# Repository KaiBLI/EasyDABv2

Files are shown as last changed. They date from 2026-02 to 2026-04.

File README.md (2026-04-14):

# EasyDABv2
Repository of info for Sergiy's EasyDABv2 DAB Exciter Board. This is not to be confused with the EasyDABv1 which is a USB-based DAB exciter board. The USB DAB Board requires a computer to handle modulation while the v2 board utilizes a FPGA for independent operation.

Assembled EasyDAB6 v2 Boards. PCBs printed with JLCPCB.

Front-side of the EasyDAB6 v2 Board
Back-side of the EasyDAB6 v2 Board

# Introducton
First off, much of this is not my original work, credit goes to Sergiy for the design and release of the EasyDAB board. His site can be found here: https://tipok.org.ua/node/46

Secondly, this is a repository of the information I've learned through trying to manufacture one of these boards myself in order that folks in the future have an easier time with it than me.
There are a couple of issues I've had to contend with, firstly, I have not been able to find a license or any information regarding copyright of this board. Given that this was done in collaboration with the OpenDigitalRadio group, it is assumed that the board was released under similar licensing to the other projects under OpenDigitalRadio, that is permitting deriative work which is also licensed under the GPL and with credit to the original creator. 

If the above is not correct and the board was released under a more restrictive license, please get in touch at hoosk@retrohoosk.tv and this repository will be updated as such. That being said, under no circumstances will documentation of my own making be removed that was created based on information that is publicly available. 

# Aims
As mentioned in the introduction, the information is somewhat sparse on how to go about creating one of these boards. The original release was an Eagle PCB project coupled with a release of the firmware for flashing the board. 

As I'm a believer in easy, accessible and transparent documentation, I have determined to document my findings and provide as much information as possible regarding the manufacture and configuration of these boards. 

So the aims of this project encompass the following:

1. Documentation

I will proceed to create an 'info dump' of all of my findings that I've learned through building this projects.

Status: 90% Done

2. Photos

I will proceed to create high-resolution and detailed photos of both empty boards and fully assembled units so that others can see what these look like once assembled.

Status: 90% Done - Still need to add empty board pictures, only have renders at this point.

3. A fresh bill of materials.

The existing bill of materials leave too much up to assumption, therefore I will create a digikey cart and an Excel sheet of components required including example part numbers. It is assumed that components over time will be obsoleted and substitutes will be required, hence specification of components will be detailed as possible.

Status: Done!

4. New Features

The board already supports DRM and FM modulation in addition to DAB/DAB+, theoretically additional FPGA core/firmware could be built for other digital modulation such as HDRadio/NRSC5 and DVB. This would require input from additional contributors familiar with FPGA programming.

Status: Help Needed

# Images 
Exported Board Renders from KiCAD:
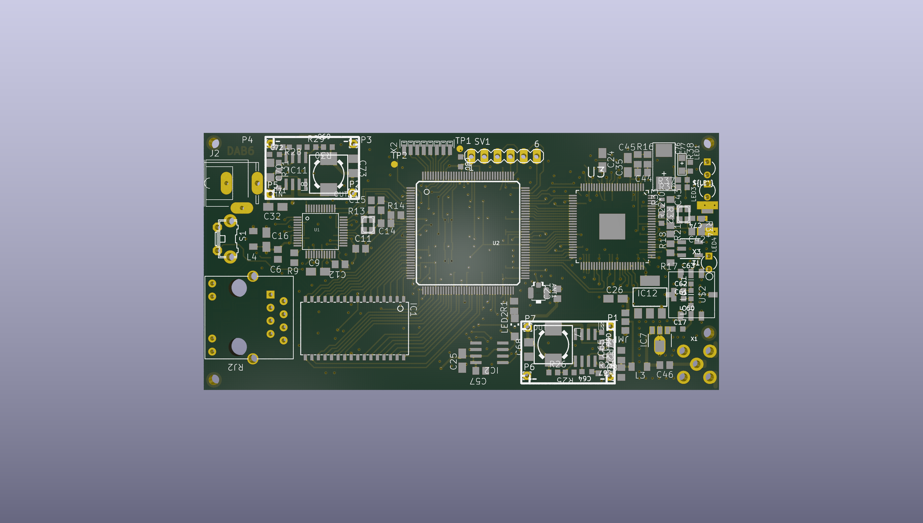
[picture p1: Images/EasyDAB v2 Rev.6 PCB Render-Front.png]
EasyDAB6v2 Front Board Render

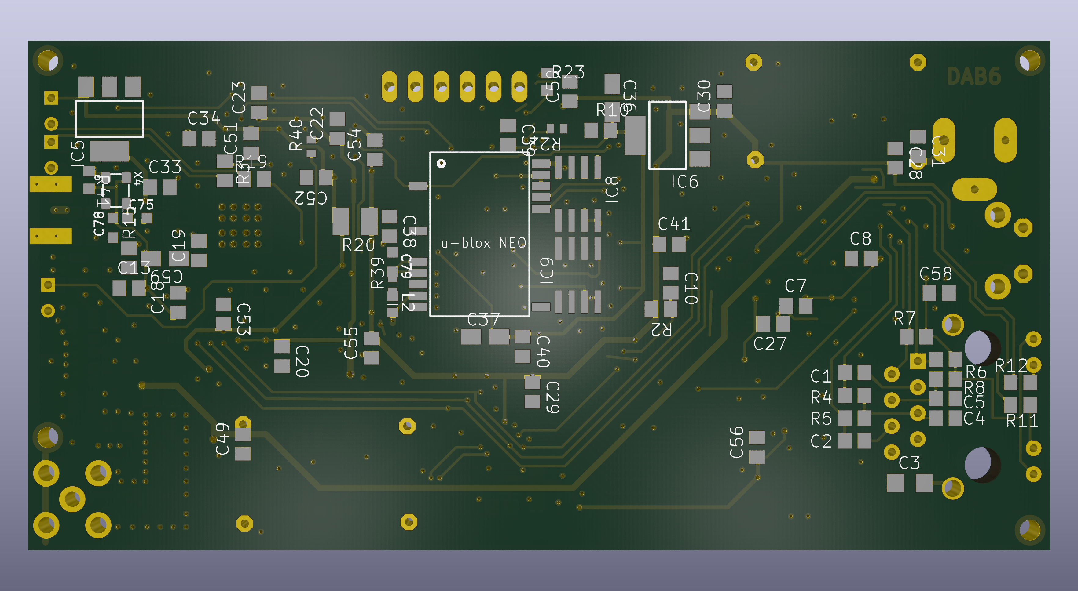
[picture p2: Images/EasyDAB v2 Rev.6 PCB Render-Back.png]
EasyDAB6v2 Back Board Render


The below are two separate concurrently operating multiplexes created using the ODR-mmbTools including ODR-DabMux, ODR-AudioEnc and ODR-PadEnc. ODR-PadEnc takes text from a file to create the DLS scrolling text and PNGs from a directory to create station logos, it then is exposed on a socket that AudioEnc can pull to add to the audio stream. ODR-AudioEnc is used to pull internet radio stations, convert them to MPEG-1 Layer II at 48kHz and provide them over an EDI or ZMQ stream to ODR-DabMux. ODR-DabMux is then used to create a DAB ensemble which is a collection of radio stations, programme data and other data compliant with the DAB standard which can then be sent to the EasyDAB modulator using ZMQ.

Home-made DAB Mux with American Radio Stations
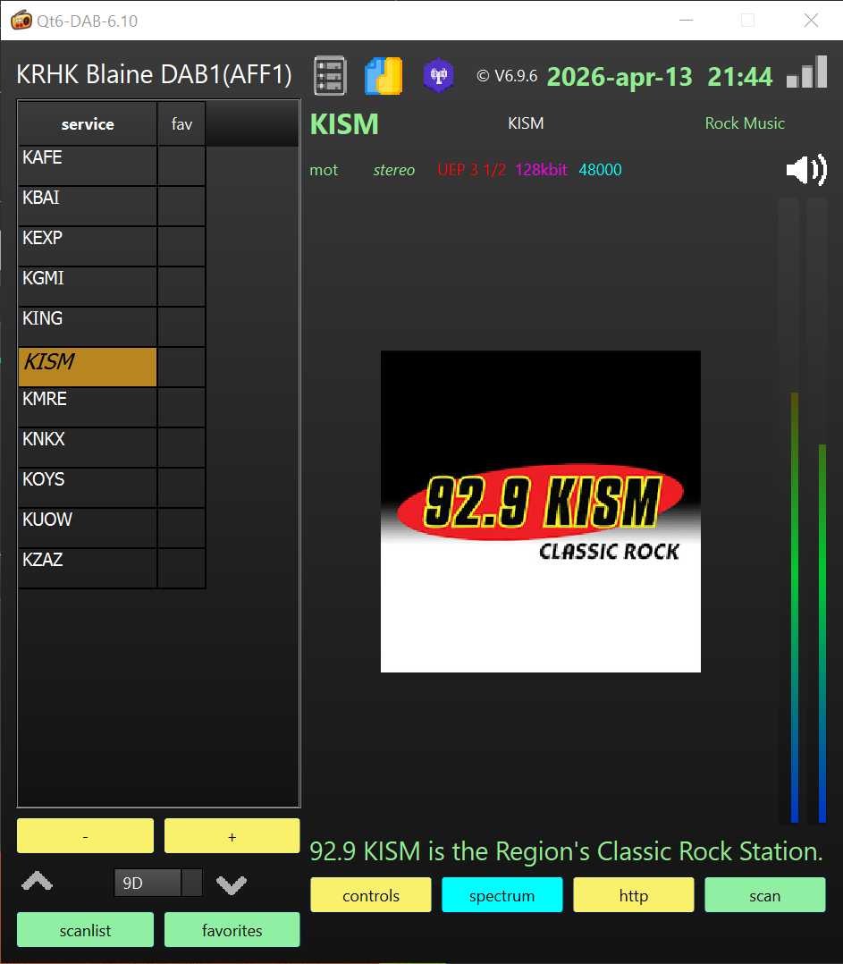
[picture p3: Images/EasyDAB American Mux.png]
Home-made DAB Mux with American Stations from Northwest Washington


Re-created BBC National DAB mux broadcasting in NW Washington
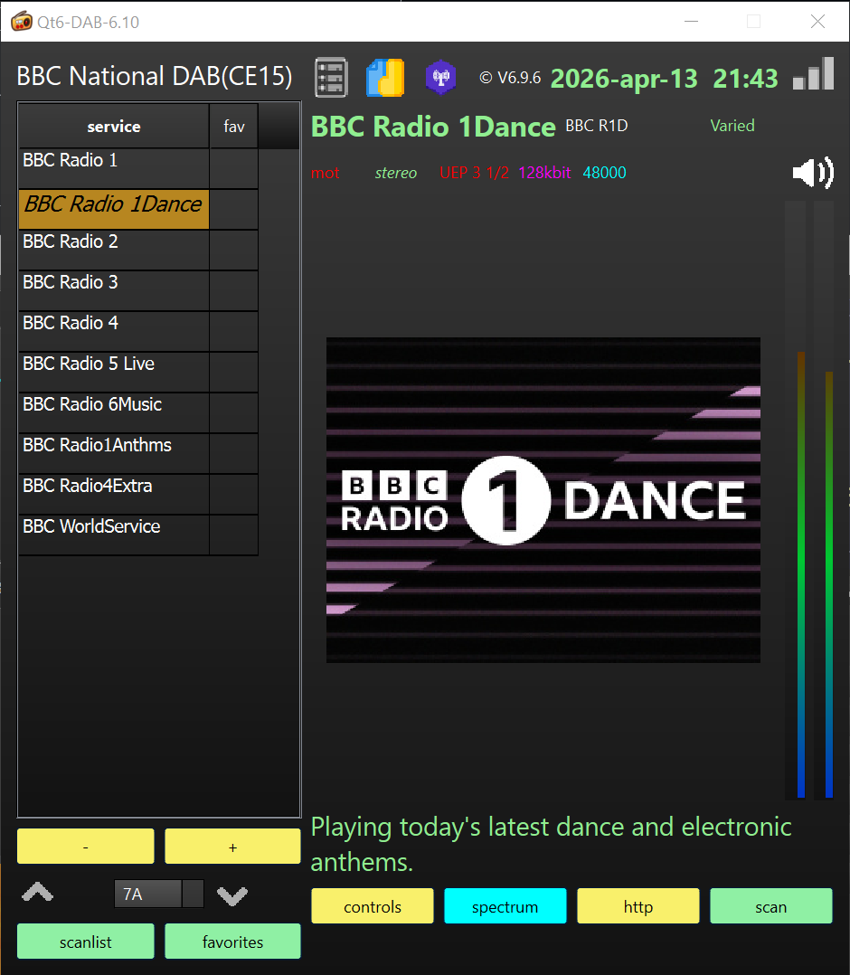
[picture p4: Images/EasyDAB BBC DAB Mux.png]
Home-made DAB Mux with re-created BBC Radio Stations in the legacy DAB Standard


Output from Qt6-DAB's SpectrumScope of the Re-created BBC National DAB Mux
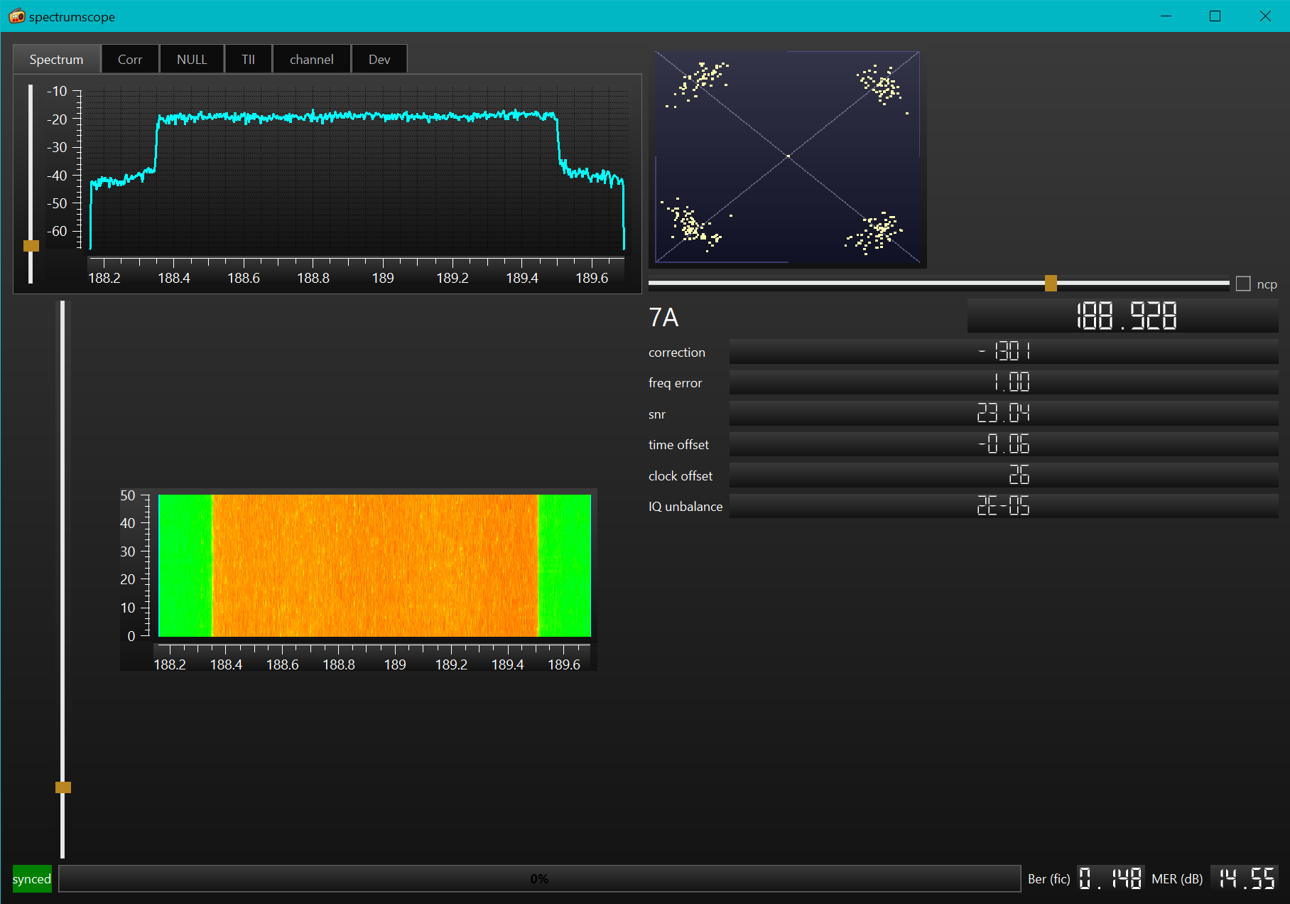
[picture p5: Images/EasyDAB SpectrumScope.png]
QT6 Spectrumscope for the re-created BBC DAB Mux


# Contact
Questions and Comments can be directed to hoosk@retrohoosk.tv , I'd love to hear your experience with assembling one of these boards and other ideas for this repo.

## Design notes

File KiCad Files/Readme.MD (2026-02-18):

# KiCAD PCB Map and Schematic
The current design of the EasyDAB PCB has a silkscreen with component labels covered by a myriad of solder pads. It is therefore essential for you to be familiar with the PCB map to accurately locate where components should go. You should not trust the PCB silkscreen to be accurate or clear on where things should go and should not be relied on. The PCB Map can be viewed by the KiCad PCB Editor, by using the search function, KiCad will highlight the appropriate solder pads for each component.

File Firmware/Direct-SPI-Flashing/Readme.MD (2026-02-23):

#This Folder Contains firmware for flashing direct to the SPI Flash

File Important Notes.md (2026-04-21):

# Noise on EasyDABv2 Cold Start
The current schematics have an issue which causes a lot of noise on cold-start which require a 2K Ohm resistor bodge. Please see here for more info: https://tipok.org.ua/node/56 - It is warned that you will burn out your output amplifier if you do not address this.

# Units are not provided for the below caps on the schematic, the correct units are Pico Farad, NOT Micro Farad. 

Thank you to PancakePuppy for confirming values.

C42 C43 - 27pF

C46 C47 - 100pF

These caps above are only required if you're using the Quartz oscillator. You do not need to install them if you are using the VCTCXO. 

# CY7C1019DV33 SRAM Chip

The main SRAM chip is designed in a socketed package, but it is generally surface mounted on this board, this can cause bad solder joints. 

If you are getting partial/no audio and evidence of corrupt DAB frames, validate the solder joints on the main SRAM, this will likely be your problem. The FPGA can appear to be fully functional with this problem happening and the only problem be the lack of audio, trust me, check the main SRAM! 

This part is End-of-Life, so it may become difficult to acquire in the future. 

# C76 Charge Pump Capacitor

If you have elected to use the VCTCXO instead of a standard Quartz Oscillator, contrary to popular belief the relatively expensive charge pump capacitor is not required for the board to operate correctly if you are not using SFN. It has not been tested without being present when configured for SFN. Please report in if you have had success without the charge-pump cap with SFN.

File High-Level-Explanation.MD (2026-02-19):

# The EasyDAB v2 Board
# What is it?
The EasyDAB v2 board is a DAB Radio exciter. It allows you to broadcast a digital radio signal compliant with DAB/DAB+ specifications that can be received on compatible DAB Digital Radios sold across Europe, certain parts of Asia and Australia.

# What is DAB?
DAB stands for Digital Audio Broadcasting, it is standard for broadcasting a digital radio signal in 55 countries around the world. It's the result of a European research project and publicly released in 1995 with consumer grade radios appearing in the late 90s. 

DAB found its earliest successes and populized widly across the UK thanks to the efforts of Pure, who manufacturered a variety of radios at a price point that was reasonable to the average consumer. The BBC and other broadcasters in the UK rapidly embraced the standard and by the early 2000s there were two national multiplexes as well as around 5 regional multiplexes broadcasting which allowed a user within range of a DAB transmitter to pick up around 40-60 radio stations broadcasting a mix of audio dramas, talk/news radio, sports as well as vast array of stations broadcasting a dynamic range of music genres. 

DAB however had a number of false starts and was abandoned in a number of other countries and only later found success with the launch of DAB+, a revision to the original standard which utilizes AAC-MP4 a codec that doubles the efficiency of transmitted audio, allowing multiplex operators to double the number of stations broadcast with no reduction of audio quality. Some countries are making plans to discontinue the use of FM radio in favor of DAB with Norway becoming the first country in the world to switch off FM broadcasts in favor of DAB+ in 2017.

The original standard of DAB utilizing MPEG-1 Layer II audio is starting to fall into disuse, the UK remaining the only country with regular DAB broadcasts with most commercial stations having switched over to the more efficient DAB+ standard. At present only the BBC National Stations as well as a small handful of commercial stations continue to broadcast in the older standard. DAB+ cannot be used by radios manufactured to the original standard and is likely to be a source of significant electronic waste in the UK.

The disuse of the original standard and the subsequent tsunami of electronic waste generated by the disposal of the earlier DAB radios popularized in the 2000s in the UK drove me to sink my teeth into this project by carrying out small-scale original DAB broadcasts here in Washington State. I'm originally from the UK, but moved over to the Pacific Northwest in 2018 bringing my DAB radios with me. They've been effective paperweights the last few years, but with this project I hope to bring them back to life, as well as preserve a selection of Pure Radio models released in the 2000s. At present I own a Pure Evoke 1, Pure Tempus 1S, Pure PocketDAB 1500 and a Pure DRX-601EX serial number 391. The Pure DRX-601EX was the first semi-portable DAB radio released, but at a high price point of GBP 500 and accordingly few were sold. DAB became popularized with the release of the Pure Evoke 1, the first sub GBP 100 DAB radio, meaning that everyone was able to get on board with DAB in the early 2000s in the UK.

# What about the Americas? 
Okay, I had to put this question in as I'm based in the US. No country in the Americas uses DAB at the time of writing. The US and Canada instead adopted Ibiquiti's IBOC (In Band On Channel) standard, officially known to the FCC as NRSC5, and to the general population as HD Radio. HD Radio is a very different standard to DAB whereby HD Radio will sandwich an analog FM or AM signal allowing the receiver to dynamically switch between analog and digital as signal conditions permit. 

DAB on the other hand uses Band III (174Mhz-240Mhz) with a wider carrier, this allows more stations to be broadcast on a single frequency and works better for countries with more centralized broadcasting approaches, while IBOC suits the highly decentralized radio market of the US. 

Of an interesting note, Canada originally did small scale experimentation with DAB on the L Band, however this was abandoned in favor of using the same standard as the US. Utilization of the L Band was removed from the DAB specification in January 2017. 

Digital Terrestrial Radio has seen lesser usage in the US and Canada due to the popularization of Satellite Radio on the L Band thanks to SiriusXM. 
Band III in the US is allocated for VHF System M Digital TV Channels 7-13 (174Mhz-216Mhz) as well as Amateur, Land Mobile, Fixed in the 216-240Mhz ranges.

# How does the EasyDAB v2 Board Work?
The EasyDAB v2 board requires a DAB Multiplex (also known as an Ensemble) to be configured and running on a server, this can be acheived by using the OpenDigitalRadio (ODR) Tools, specifically ODR-AudioEnc to process an audio source into a compatible format for DAB use and ODR-DabMux to build an Ensemble. Additionally you may want to use ODR-PadEnc to provide Programme Additional Data to your broadcasted stations. For reference, a multiplex/ensemble is a collection of audio and data services packaged together and provided in a ZMQ or ETI stream to be received by the EasyDAB board.

The EasyDAB board has a Xilinx Spartan 6 FPGA configured to handle the DAB modulation after which it sends the data to a Digital Synthesiser to generate the digital frequency. It then passes through a mini baulin to step up the frequency strength, through either a low pass filter or a band pass filter (Depending on your config), through a Low Noise Amplifier and out to a SMA Jack to a broadcast antenna. The generated signal can then be received on DAB/DAB+ hardware. 

If you are using a Low Pass Filter, you can load alternative firmware onto the board to broadcast FM or Digital Radio Mondiale signals.

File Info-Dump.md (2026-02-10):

# EasyDAB v2 Assembly Options
The EasyDAB v2 is a versitile board allowing for usage with transmitting a DAB ensemble from a single board and using multiple EasyDAB v2 boards to extend the range of your broadcast ensemble. If you wish to build for usage with a SFN there are additional components and considerations you need to make which are covered in this document. Additionally, you can build initially for non-SFN usage and later add the SFN components to enable that functionality. SFN does add a significant cost to the assembly of the board, so you will probably only want to use those components if you are certain you want to go down the SFN route, and that to gain any benefit from purchasing those components you will actually need to double up that order as SFN requires at least two EasyDAB v2 boards. The author of this document has yet to experiment with SFN usage, so much of this information I have obtained by examining schematics and obtaining information from other members of the OpenDigitalRadio Telegram group. Big thanks to Rash for providing some high-level information that has allowed me to sink my teeth into this project. 

This document also covers your options for acheiving RF filtering, which is a non-optional step you must take to avoid polluting the RF spectrum with harmonics as well as the decision whether to utilize the Mini360 DC-DC converter modules or source our own equivalent components for directly soldering on the board. 

As a word of advice for people starting out, I would suggest startin off with the options installing the Mini360 modules, the RBP-204+ band pass filter and electing to -not- install the SFN components.

Final bit of advice, I would suggest gaining some experience with soldering before engaging on this project. A number of the ICs such as the FPGA and Digital Synthesiser are fairly expensive and have a very high pin density. Good solder, good flux, a steady hand as well as a microscope is required! 

# 1. The Mini360 Modules

The Mini360 Modules are a convenient way of obtaining required voltages for the EasyDAB v2 board to work. However, one may desire to forgo the Mini360's to instead directly solder on the required circuitry directly on the board to acheive the required voltages. If you utilize the BoM from the Eagle Project, you will have components included on that BoM that are only needed if you are going the route to directly solder the DC-DC components to the board.

Each EasyDAB board requires two Mini360 DC-DC step-down buck converter modules. The Mini360 takes an input voltage of 4.75v-23v and can output between 1.0v-17v. The output is both determined by the input voltage and the configuration of the potentiometer located on the board.
The EasyDAB will supply both boards with 5v, but each needs to be configured for different output voltages. 

The Mini-360 Module closest to the DC Barrel Jack with IC11 labelled on the PCB must output 3.3v (Potentiometer configured for 21.5kOhm), while the Mini-360 module closest to the RF_OUT with IC10 labelled on the PCB must be configured for 1.8v output (Potentiometer configured for 7.87kOhm). It is advisable to run in 5v with a dummy load on the module's output and ensure that the potentiometers are configured for the correct output voltages BEFORE installing on the module. 

**Direct Solder Pads**
For reference the Mini360 direct-solder pads are labelled as follows, if you plan to use the Mini360 modules rather than direct solder you can exclude the below components from your bill of materials:

_DC Side (5v Input - 3.3v Output)_

C31 0.1uF

C32 4.7uF

C70 10uF

C71 10nF

C72 100nF

C73 22uF

R27 6.8K

R28 6.8K

R29 8K2

R30 21.5K

R31 (Potentiometer) 10-100K

L8 10uH

IC11 MP2307

_RF Side (5v Input - 1.8v Output)_

C68 22uF

C67 100nF

C65 10uF

C66 10nF

C64 3.9nF

R24 6.8K

R25 8K2

R26 7.87K

R27 (Potentiometer) 10-100K

L7 10uH Inductor

IC10 MP2307 DC>DC

# 2. Band Pass Filter / Low Pass Filter

The band pass filter is perhaps the easier option for acheiving RF filtering of the outputted signal. RF filtering is essential if you are using the EasyDAB board outside of a RF shielded box. This is because an unfiltered signal will spread RF harmonics all over the spectrum potentially interfering with licensed services and other lawful users of the RF spectrum. You could get in significant trouble with the associated regulatory bodies in your country if you do not filter your signal! However, there are three options to acheive RF filtering. You can either use the RBP-204+, the RBP-220+ or a set of passive componenets. The below covers the advantages and disadvantages of these options.

**RBP-204+**

_Advantages:_

Covers RF filtering for the entirety of the DAB Band III spectrum of 174Mhz-240Mhz. 

Probably acheives the cleanest signal possible.

Easier than using the series of passive components.

_Disadvantages:_

Expensive Component

Out-of-stock at some suppliers

Needs to be swapped for a different RF filtering option if you decided to change the board to be used for FM or DRM usage.

**RBP-220+**

_Advantages:_

Possibly easier to source than RBP-204+

Easier than using series of passive components.

_Disadvantages_

Does not cover entirety of DAB Band III, only covers to 212Mhz-240Mhz

Needs to be swapped for a different RF filtering option if you decided to change the board to be used for FM or DRM usage.

**Inductors and Capacitors / Low Pass Filter**

One can forgo the RBP-204+/RBP-220+ and instead install a series of capacitors and inductors at the locations of L1, L5 and L6, and C63, C62, C61 and C60. 

This may(?) acheive a lesser quality of filtering, however has the advantage of utilizing cheaper components. Additionally, if one wishes to use the EasyFM firmware, this should work for that too. (This I have not been able to test, Sergiy's site only mentions the usage of low pass filtering instead of band pass filtering for EasyFM - I ASSUME that references the circit diagram of using the inductors/capacitors)

_Advantages:_

Easiest and cheapest components to source

Works for EasyFM(tbc)

_Disadvantages_

Possibly lesser quality of filtering

More soldering and quantity of components to source

# 3. Single Frequency Network (SFN)
The EasyDAB v2 board allows you to use multiple boards to create a single frequency network of transmitters. That is you can extend your range by broadcasting the same multiplex on the same frequency over a distributed area. However, for this to work, all the ones and zeros must be sent out of all the transmitter in perfect synchronization. To acheive this, a GPS module is used to timestamp frames allowing the transmitters to broadcast said frames at the same time. 

Most folks who are looking to build microtransmitters within their own home or properties will most likely not need this. You will probably have an easier time boosting the power of your signal to acheive the desired range rather than needing to go down the SFN tunnel. However, if you are restricted by power limitations on restricted license/no-license regulations from your jurisdiction, you may find SFN useful as the regulations may be silent on the -quantity- of transmitters on the same frequency as such regulations usually only stipulate power of individual broadcasts. 

Using the design of Sergiy's board, you can initially build for non-SFN usage and later upgrade to the components needed for SFN at a later date if desired. 

The components required for SFN are as follows and can be excluded from your BoM if you do not need SFN:

_VCTCXO_

X4 - 19.2Mhz OPL Crystal Oscellator

R36 - 10k

R37 - 100k

R38 - 100k

R41 - 100k

C75 - 10nF

C78 - 100n

_RF In_

REF_IN - SMA Connector

C74 - 10nF

R34 - 50Ohm

_Ublox NEO-M8N_

u-blox NEO - GPS IC

L2 - 33nH

C79 - 100nF

C80 - 100nF

R39 - 10R

R40 - 1K

LED4 - 1PPS

_SFN also needs the Additional SRAM_

You may yield additional benefits such as board stability when receiving a ETI stream if you install the additional SRAMs regardless. I would therefore advise doing so regardless unless you are really pinched for costs. 

IC8 - 23LC1024

IC9 - 23LC1024

_If you are building for Non-SFN Usage_

You must install

R21 - 1M

Q2 - 24.576Mhz Clock Oscellator

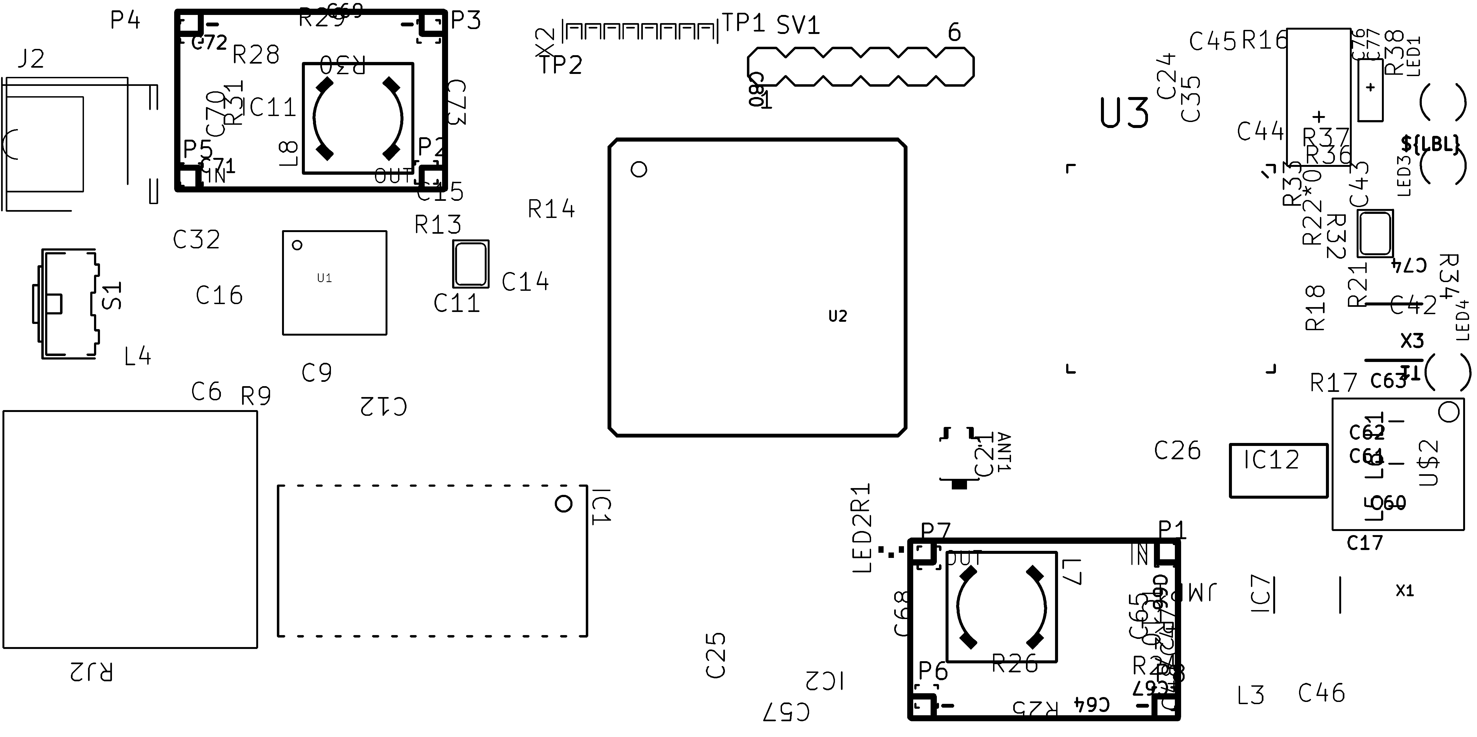
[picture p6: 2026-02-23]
Gerber/GBRFiles/GBR_10578116_1_top.png

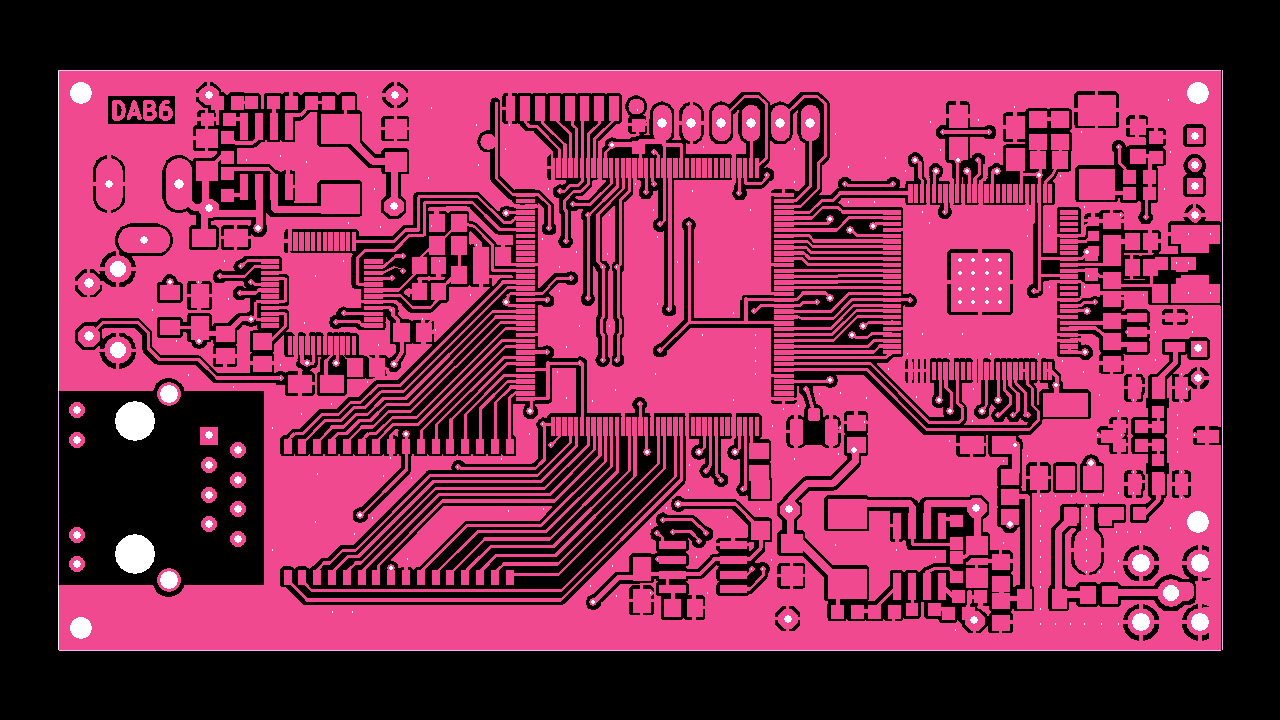
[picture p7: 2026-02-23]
Gerber/GBRFiles/GBR_10578116_1_snapshot.png

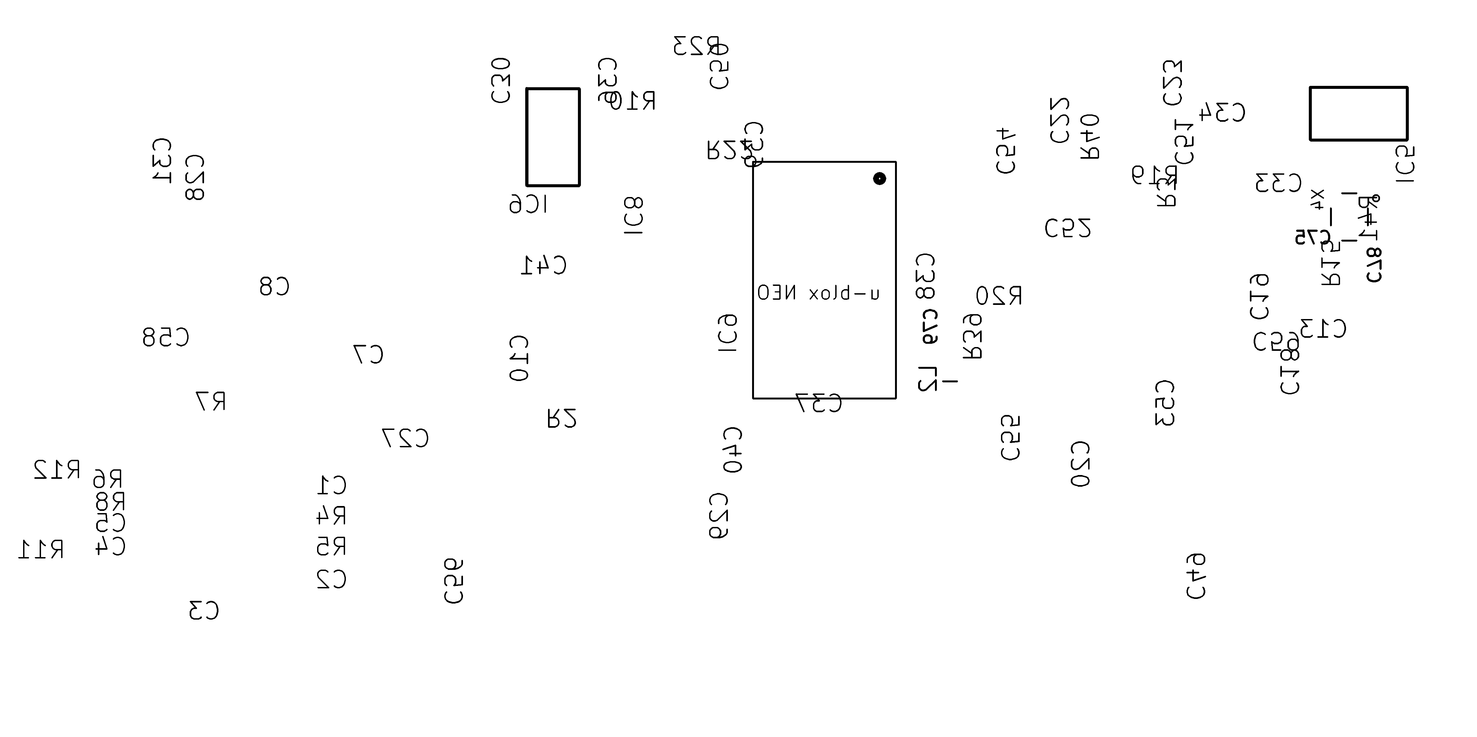
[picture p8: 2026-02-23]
Gerber/GBRFiles/GBR_10578116_1_bottom.png

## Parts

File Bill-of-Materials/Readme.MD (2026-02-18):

# This Folder Contains Exported and Cleaned Up Bill of Materials Sheets.

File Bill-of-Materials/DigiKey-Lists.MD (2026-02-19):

# DigiKey Parts Lists

# DAB Board Main

The ICs have been separated from the passives as you may wish to source the ICs from a cheaper source than DigiKey, FPGAs and DACs can be found on eBay for a significant discounts, but come with the added risk of being non-genuine parts. 

Essential ICs (FPGA/DAC/Main SRAM/Ethernet Controller): https://www.digikey.com/en/mylists/list/T6NBFB3ZXT

Essential Components: https://www.digikey.com/en/mylists/list/4SKKTAJE6A

Essential SPI Flash: A SPI Flash is requried which stores the FPGA Core and the Firmware, the part number of the original design is M25P16 S0-08 Gull Wing Package, however other components may be compatible. You will need to source this separately as it is marked as obsolite by DigiKey and is no longer stocked. eBay Source here: https://www.ebay.com/itm/334848598580

Essential RJ-45 Jack: The HR911105A RJ-45 Jack does not appear to be available on DigiKey, you will need to source it elsewhere. Here's an example listing: https://www.lcsc.com/product-detail/C12074.html

Essential DC-DC Converters: The Mini360 DC-DC Buck Converter required for 3.3v and 1.8v on the board does not appear to be available at DigiKey, but it can be found at many other suppliers such as Amazon, eBay and AliExpress, here's an example listing from RobotShop https://www.robotshop.com/products/mini-360-dc-dc-buck-converter .

Note: The DC Jack's Holes are drilled very small on the PCB, you may have to reduce the leg size of the DC barrel jack you obtain. 

# SRAM Option (Strongly Recommended)
23LC1024 SRAM: https://www.digikey.com/en/mylists/list/1WGT9OCI7E

# DAC Oscillator Options (One of Two of the Below is Required)

TC Oscillator (Strongly Recommended): https://www.digikey.com/en/mylists/list/RGXW9F6W7X

Quartz Oscillator: https://www.digikey.com/en/mylists/list/ATKNHPW9MJ

# Filtering Options (One of Two of the Below is Required)

Low Pass Filter (Needed for EasyFM/EasyDRM - Harder to Install): https://www.digikey.com/en/mylists/list/UZGJUMNWCD

Band Pass Fiter (Only Supports DAB Band III Frequencies - Easier to Install): https://www.digikey.com/en/mylists/list/YETD7D4YD4

# GPSDO Option (Only needed for SFN)

IF you wish to use SFN, you will need at least two EasyDAB boards configured with a TC Oscillator, additional SRAMs and the GPSDO module. 
GPSDO: https://www.digikey.com/en/mylists/list/PNWZ96SRTK

Additionally a surface mount GPS antenna RF In is reqired at the REF_IN location on the board so the GPSDO can get a signal. I'm not sure what component fits the requirements for this.

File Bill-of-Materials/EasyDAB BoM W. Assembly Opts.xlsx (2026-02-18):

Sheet: EasyDAB Main
Reference Designators | Quantity | Description | Package | Value | Manufacturer P/N | Comments | Vendor | Vendor Part Number | Top/Bottom
C1 | 1 | CAPACITOR | C0805 | 6.8 nF |  |  |  |  | Bottom
C10 | 1 | CAPACITOR | C0805 | 0.1 uF |  |  |  |  | Bottom
C11 | 1 | CAPACITOR | C0805 | 0.1 uF |  |  |  |  | Top
C12 | 1 | CAPACITOR | C0805 | 10 nF |  |  |  |  | Top
C13 | 1 | CAPACITOR | C0805 | 0.1 uF |  |  |  |  | Bottom
C14 | 1 | CAPACITOR | C0805 | 18pF |  |  |  |  | Top
C15 | 1 | CAPACITOR | C0805 | 18 pF |  |  |  |  | Top
C16 | 1 | Chip Capacitor Type KEMET A / EIA 3216-18 reflow solderKEMET S / EIA 3216-12 | A/3216-18R | 10 uF |  |  |  |  | Top
C17 | 1 | SMD CHIP CAP | 0603 | 1 nF |  |  |  |  | Top
C18 | 1 | CAPACITOR | C0805 | 0.1 uF |  |  |  |  | Bottom
C19 | 1 | CAPACITOR | C0805 | 0.1 uF |  |  |  |  | Bottom
C2 | 1 | CAPACITOR | C0805 | 6.8 nF |  |  |  |  | Bottom
C20 | 1 | CAPACITOR | C0805 | 0.1 uF |  |  |  |  | Bottom
C21 | 1 | CAPACITOR | C0805 | 0.1 uF |  |  |  |  | Top
C22 | 1 | CAPACITOR | C0805 | 0.1 uF |  |  |  |  | Bottom
C23 | 1 | CAPACITOR | C0805 | 0.1 uF |  |  |  |  | Bottom
C24 | 1 | Chip Capacitor Type KEMET A / EIA 3216-18 reflow solderKEMET S / EIA 3216-12 | A/3216-18R | 4.7 uF |  |  |  |  | Top
C25 | 1 | Chip Capacitor Type KEMET A / EIA 3216-18 reflow solderKEMET S / EIA 3216-12 | A/3216-18R | 4.7 uF |  |  |  |  | Top
C26 | 1 | Chip Capacitor Type KEMET A / EIA 3216-18 reflow solderKEMET S / EIA 3216-12 | A/3216-18R | 4.7uF |  |  |  |  | Top
C27 | 1 | CAPACITOR | C0805 | 0.1 uF |  |  |  |  | Bottom
C28 | 1 | CAPACITOR | C0805 | 0.1 uF |  |  |  |  | Bottom
C29 | 1 | CAPACITOR | C0805 | 0.1 uF |  |  |  |  | Bottom
C3 | 1 | CAPACITOR | C1206 | 1uF |  |  |  |  | Bottom
C30 | 1 | CAPACITOR | C0805 | 0.1 uF |  |  |  |  | Bottom
C33 | 1 | CAPACITOR | C0805 | 0.1 uF |  |  |  |  | Bottom
C34 | 1 | CAPACITOR | C0805 | 0.1 uF |  |  |  |  | Bottom
C35 | 1 | Chip Capacitor Type KEMET A / EIA 3216-18 reflow solderKEMET S / EIA 3216-12 | A/3216-18R | 4.7 uF |  |  |  |  | Top
C36 | 1 | Chip Capacitor Type KEMET A / EIA 3216-18 reflow solderKEMET S / EIA 3216-12 | A/3216-18R | 4.7 uF |  |  |  |  | Bottom
C37 | 1 | Chip Capacitor Type KEMET A / EIA 3216-18 reflow solderKEMET S / EIA 3216-12 | A/3216-18R | 4.7 uF |  |  |  |  | Bottom
C38 | 1 | CAPACITOR | C0805 | 0.1 uF |  |  |  |  | Bottom
C39 | 1 | CAPACITOR | C0805 | 0.1 uF |  |  |  |  | Bottom
C4 | 1 | CAPACITOR | C0805 | 10 nF |  |  |  |  | Bottom
C40 | 1 | CAPACITOR | C0805 | 0.1 uF |  |  |  |  | Bottom
C41 | 1 | CAPACITOR | C0805 | 0.1 uF |  |  |  |  | Bottom
C42 | 1 | CAPACITOR | C0805 | 27pF |  |  |  |  | Top
C43 | 1 | CAPACITOR | C0805 | 27pF |  |  |  |  | Top
C44 | 1 | CAPACITOR | C0805 | 43 pF |  |  |  |  | Top
C45 | 1 | CAPACITOR | C0805 | 270 pF |  |  |  |  | Top
C46 | 1 | CAPACITOR | C0805 | 100 pF |  |  |  |  | Top
C47 | 1 | CAPACITOR | C0805 | 100 pF |  |  |  |  | Top
C48 | 1 | CAPACITOR | C0805 | 0.1 uF |  |  |  |  | Top
C49 | 1 | CAPACITOR | C0805 | 0.1 uF |  |  |  |  | Bottom
C5 | 1 | CAPACITOR | C0805 | 22 nF |  |  |  |  | Bottom
C50 | 1 | CAPACITOR | C0805 | 0.1 uF |  |  |  |  | Bottom
C51 | 1 | CAPACITOR | C0805 | 0.1 uF |  |  |  |  | Bottom
C52 | 1 | CAPACITOR | C0805 | 0.1 uF |  |  |  |  | Bottom
C53 | 1 | CAPACITOR | C0805 | 0.1 uF |  |  |  |  | Bottom
C54 | 1 | CAPACITOR | C0805 | 0.1 uF |  |  |  |  | Bottom
C55 | 1 | CAPACITOR | C0805 | 0.1 uF |  |  |  |  | Bottom
C56 | 1 | CAPACITOR | C0805 | 0.1 uF |  |  |  |  | Bottom
C57 | 1 | CAPACITOR | C0805 | 0.1 uF |  |  |  |  | Top
C58 | 1 | CAPACITOR | C0805 | 0.1 uF |  |  |  |  | Bottom
C59 | 1 | Chip Capacitor Type KEMET A / EIA 3216-18 reflow solderKEMET S / EIA 3216-12 | A/3216-18R | 4.7 uF |  |  |  |  | Bottom
C6 | 1 | CAPACITOR | C0805 | 0.1 uF |  |  |  |  | Top
C7 | 1 | CAPACITOR | C0805 | 0.1 uF |  |  |  |  | Bottom
C8 | 1 | CAPACITOR | C0805 | 0.1 uF |  |  |  |  | Bottom
C9 | 1 | Chip Capacitor Type KEMET A / EIA 3216-18 reflow solderKEMET S / EIA 3216-12 | A/3216-18R | 4.7 uF |  |  |  |  | Top
IC1 | 1 | 32-pin TSOP II (51-85095) – Voltage Reglator | TSOPII-32 | CY7C1019DV33-10ZXCI |  | Main SRAM for FPGA |  |  | Top
IC12 | 1 | Small Outline Transistor 223 | SOT223 | LD117AS33TR |  | Voltage Regulator |  |  | Top
IC2 | 1 | Small Outline Narrow Plastic Gull Wing – SPI Flash | SO-08 | M25P16 | 25LC080/SN | SPI Flash for FPGA Bitstream |  |  | Top
IC5 | 1 | Small Outline Transistor 223 – Voltage Regulator | SOT223 | LD117AS18TR |  | Voltage Regulator |  |  | Bottom
IC6 | 1 | Small Outline Transistor 223 – Voltage Regulator | SOT223 | LD117AS12TR |  | Voltage Regulator |  |  | Bottom
IC7 | 1 | SOT98 PK (R-PDSO-G3) Low Noise Amplifier | SOT89 | SPF5189Z |  | Low Noise Amplifier to Step up RF |  |  | Top
J2 | 1 | DC POWER JACK 2mm Right Angle, Through Hole, Rated 5A at 16VDC, PC Terminals | SPC4077 | POWER |  | DC Barrel Jack |  |  | Top
JMP1 | 1 | 0R Jumper Variant A | A0R-JMP | 0R-JUMPA |  | 3.3 / 5v Jumper for Antenna Power |  |  | Top
L3 | 1 | INDUCTOR | L3216C | 1 uH |  |  |  |  | Top
L4 | 1 | INDUCTOR | L3216C | 1 uH |  |  |  |  | Top
LED1 | 1 | LED | LED2-2.54-D3.0MM | CX-G302DC | CX-G302DC | ETI Not Ready LED |  |  | Top
LED2 | 1 | CHIPLED | CHIPLED_1206 | NOT_LOADED |  | Empty FPGA Warning LED |  |  | Top
LED3 | 1 | LED | LED2-2.54-D3.0MM | CX-G302DC | CX-G302DC | PLL Lock LED |  |  | Top
Q1 | 1 | FPGA Oscillator | NX3225 | 25MHz |  | Drives FPGA at 25Mhz |  |  | Top
R1 | 1 | RESISTOR | M0805 | 680 Ohm |  |  |  |  | Top
R10 | 1 | RESISTOR | R0805 | 150 Ohm |  |  |  |  | Bottom
R11 | 1 | RESISTOR | R0805 | 330 Ohm |  |  |  |  | Bottom
R12 | 1 | RESISTOR | R0805 | 330 Ohm |  |  |  |  | Bottom
R13 | 1 | RESISTOR | R0805 | 1M Ohm |  |  |  |  | Top
R14 | 1 | RESISTOR | R0805 | 0 Ohm |  |  |  |  | Top
R15 | 1 | RESISTOR | R0805 | 10k Ohm |  |  |  |  | Bottom
R16 | 1 | RESISTOR | R0805 | 1.3K Ohm |  |  |  |  | Top
R17 | 1 | RESISTOR | R0805 | 49.9 Ohm |  |  |  |  | Top
R19 | 1 | RESISTOR | M0805 | 680 Ohm |  |  |  |  | Bottom
R2 | 1 | RESISTOR | M0805 | 10K Ohm |  |  |  |  | Bottom
R20 | 1 | RESISTOR | R1210 | 0 Ohm |  |  |  |  | Bottom
R22* | 1 | RESISTOR | R0603 | 47K Ohm(opt) |  |  |  |  | Top
R23 | 1 | RESISTOR | R0603 | 1k |  |  |  |  | Bottom
R3 | 1 | RESISTOR | M0805 | 300 Ohm |  |  |  |  | Bottom
R4 | 1 | RESISTOR | R0805 | 49.9 Ohm |  |  |  |  | Bottom
R5 | 1 | RESISTOR | R0805 | 49.9 Ohm |  |  |  |  | Bottom
R6 | 1 | RESISTOR | R0805 | 49.9 Ohm |  |  |  |  | Bottom
R7 | 1 | RESISTOR | R0805 | 49.9 Ohm |  |  |  |  | Bottom
R8 | 1 | RESISTOR | R0805 | 10 Ohm |  |  |  |  | Bottom
R9 | 1 | RESISTOR | R0805 | 12.4k Ohm |  |  |  |  | Top
RJ2 | 1 | RJ-45 Jack | HR911105A | HR911105A |  | Ethernet Jack |  |  | Top
S1 | 1 | OMRON SWITCH | B3F-31XX | RESET |  | Reset Switch |  |  | Top
T1 | 1 | RT TRANSFORMER | AT224-3 | TC1-1T+ |  | Mini Transformer to Step up RF |  |  | Top
U1 | 1 | Network Chip | W5500 | W5500 |  | Network Chip for TCP/IP and ETI |  |  | Top
U2 | 1 | FPGA TQ144 TQG144 | TQ144 | 6SLX9TQG144 |  | FPGA for Firmware and Modulation |  |  | Top
U3 | 1 | Digital Synthesizer | QFP50P1600X1600X120-101N | AD9957BSVZ |  | Digital Synth to Excite Digital RF |  |  | Top
X1 | 1 | SMA DIP Connector 90° 50 Ohm | SMA90_DIP | RF_OUT |  | Antenna Out |  |  | Top
X2 | 1 | 1.27mm SINGLE ROW FEMALE SOCKET | 1296-08 | 1296-T08 |  | FPGA JTAG |  |  | Top

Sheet: Additional SRAM
Reference Designators | Quantity | Description | Package | Value | Manufacturer | Comments | Vendor | Vendor Part Number | Top/Bottom
IC8 | 1 | Small Outline Narrow Plastic Gull Wing | SO-08 | 23LC1024 |  | Additional SRAM IC |  |  | Bottom
IC9 | 1 | Small Outline Narrow Plastic Gull Wing | SO-08 | 23LC1024 |  | Additional SRAM IC |  |  | Bottom
R22 | 1 | RESISTOR | R0402 | 0 Ohm |  | Enables Board to Recognize SRAM |  |  | Bottom

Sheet: DC-DC Converters (Mini360 Modul
Reference Designators | Quantity | Description | Package | Value | Manufacturer | Comments | Vendor | Vendor Part Number | Top/Bottom
Unmarked | 1 | Mini360 DC-DC Buck Converter Module (DC Barrel Jack Side) | Custom | Output 3.3v |  | Mini360 Module – Requires configuration of Pot to 3.3v
Unmarked | 1 | Mini360 DC-DC Buck Converter Module (RF SMA Jack Side) | Custom | Output 1.8v |  | Mini360 Module – Requires configuration of Pot to 1.8v

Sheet: DC-DC Converters (Direct Solder
Reference Designators | Quantity | Description | Package | Value | Manufacturer | Manufacturer Part Number (MPN) | Vendor | Vendor Part Number | Top/Bottom
C70 | 1 | CAPACITOR | C1206 | 10 uF |  |  |  |  | Top
C71 | 1 | SMD CHIP CAP | 0603 | 10 nF |  |  |  |  | Top
C32 | 1 | Chip Capacitor Type KEMET A / EIA 3216-18 reflow solderKEMET S / EIA 3216-12 | A/3216-18R | 4.7uF |  |  |  |  | Top
IC11 | 1 | 8-Lead Small Outline IC (SO-8) | SO8 | MP2307 |  |  |  |  | Top
L8 | 1 | High Power Density, High Efficiency, Shielded Inductors | DR74 | 10 uH |  |  |  |  | Top
C31 | 1 | CAPACITOR | C0805 | 0.1 uF |  |  |  |  | Bottom
C73 | 1 | CAPACITOR | C1206 | 22uF |  |  |  |  | Top
C72 | 1 | SMD CHIP CAP | 0603 | 100 nF |  |  |  |  | Top
R31 | 1 | RESISTOR | R0603 | 10K-100K Ohm Potentiomter |  |  |  |  | Top
C69 | 1 | SMD CHIP CAP | 0603 | 3.9 nF |  |  |  |  | Top
R28 | 1 | RESISTOR | R0603 | 6.8K Ohm |  |  |  |  | Top
R30 | 1 | RESISTOR | R0603 | 21.5K* (for 3v3) Ohm |  |  |  |  | Top
R29 | 1 | RESISTOR | R0603 | 8.2K Ohm* |  |  |  |  | Top
C65 | 1 | CAPACITOR | C1206 | 10 uF |  |  |  |  | Top
C66 | 1 | SMD CHIP CAP | 0603 | 10 nF |  |  |  |  | Top
IC10 | 1 | 8-Lead Small Outline IC (SO-8) | SO8 | MP2307 |  |  |  |  | Top
L7 | 1 | High Power Density, High Efficiency, Shielded Inductors | DR74 | 10 uH |  |  |  |  | Top
C68 | 1 | CAPACITOR | C1206 | 22 uF |  |  |  |  | Top
C67 | 1 | SMD CHIP CAP | 0603 | 100 nF |  |  |  |  | Top
R27 | 1 | RESISTOR | R0603 | 10...100K (Potentiometer) |  |  |  |  | Top
C64 | 1 | SMD CHIP CAP | 0603 | 3.9 nF |  |  |  |  | Top
R24 | 1 | RESISTOR | R0603 | 6.8K Ohm |  |  |  |  | Top
R26 | 1 | RESISTOR | R0603 | 7.87K* Ohm (for 1v8) |  |  |  |  | Top
R25 | 1 | RESISTOR | R0603 | 8.2K* Ohm |  |  |  |  | Top

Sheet: Quartz DAC Oscillator Component
Reference Designators | Quantity | Description | Package | Value | Manufacturer | Comments | Vendor | Vendor Part Number | Top/Bottom
Q2 | 1 |  | NX3225 | 24.576MHz |  | Quartz Oscillator |  |  | Top
R21 | 1 | RESISTOR | R0805 | 1M Ohm |  |  |  |  | Top
R32 | 1 | RESISTOR | R0402 | 0 Ohm |  | Toggles use of Quarts Oscillator |  |  | Top

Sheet: TC DAC Oscillator Components
Reference Designators | Quantity | Description | Package | Value | Manufacturer | Comments | Vendor | Vendor Part Number | Top/Bottom
X4 | 1 |  | X4-SMD-3.2X2.5X0.7MM | 19.2MHZ |  | VCTCXO – Temperature Controlled Oscillator |  |  | Bottom
R33 | 1 | RESISTOR | R0402 | 0 Ohm |  | Enables VCTCXO instead of Quartz Oscillator |  |  | Top
R37 | 1 | RESISTOR | R0603 | 100K Ohm |  |  |  |  | Top
R38 | 1 | RESISTOR | R0603 | 100k Ohm (optional) |  |  |  |  | Top
C77 | 1 |  | AVX-A | 10 uF | TAJA106K010RNJ |  |  |  | Top
C76 | 1 |  | AVX-D | 220 uF |  |  |  |  | Top
R36 | 1 | RESISTOR | R0603 | 10k Ohm |  |  |  |  | Top
R41 | 1 | RESISTOR | R0603 | 100K Ohm |  |  |  |  | Bottom
C78 | 1 | SMD CHIP CAP | 0603 | 100 nF |  |  |  |  | Bottom
C75 | 1 | SMD CHIP CAP | 0603 | 10 nF |  |  |  |  | Bottom

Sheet: GPS Components
Reference Designators | Quantity | Description | Package | Value | Manufacturer | Manufacturer Part Number (MPN) | Vendor | Vendor Part Number | Top/Bottom
U$1 | 1 | u-blox NEO GNSS module | NEO-M8 | NEO-M8 |  |  |  |  | Bottom
ANT1 | 1 |  | U-FL3P-SMD-2.6X2.6X1.0MM | U-FL |  |  |  |  | Top
L2 | 1 |  | INDC1608X95N | 33 nH |  |  |  |  | Bottom
R39 | 1 | RESISTOR | R0402 | 10 Ohm |  |  |  |  | Bottom
C79 | 1 | SMD CHIP CAP | 0603 | 100 nF |  |  |  |  | Bottom
LED4 | 1 | LED | LED2-2.54-D3.0MM | 1 PPS |  | Y304DC |  |  | Top
R40 | 1 | RESISTOR | R0402 | 1K Ohm |  |  |  |  | Bottom
C80 | 1 | SMD CHIP CAP | 0603 | 100 nF |  |  |  |  | Top
X3 | 1 |  | W5500_LX9_AD9957_SMA_EDGELAUNCH_UFL | REF_IN |  |  |  |  | Top
C74 | 1 | SMD CHIP CAP | 0603 | 10 nF (DNI)
R34 | 1 | RESISTOR | R0402 | 50 Ohm (DNI) |  |  |  |  | Top

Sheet: Band Pass Filter
Reference Designators | Quantity | Description | Package | Value | Manufacturer | Manufacturer Part Number (MPN) | Vendor | Vendor Part Number | Top/Bottom
U$2 | 1 |  | GP731 | RBP-204+ |  | Filters out RF Harmonics and passes only 175-237Mhz – Use Low Pass Filter for EasyFM or EasyDRM Use |  |  | Top

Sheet: Low Pass Filter
Reference Designators | Quantity | Description | Package | Value | Manufacturer | Manufacturer Part Number (MPN) | Vendor | Vendor Part Number | Top/Bottom
R18 | 1 | RESISTOR | R0805 | 49.9 Ohm |  |  |  |  | Top
C63 | 1 | SMD CHIP CAP | 0603 | 16 pF* |  |  |  |  | Top
L1 | 1 |  | INDC1608X95N | 47 nH* |  |  |  |  | Top
C62 | 1 | SMD CHIP CAP | 0603 | 27 pF* |  |  |  |  | Top
L6 | 1 |  | INDC1608X95N | 56 nH* |  |  |  |  | Top
C61 | 1 | SMD CHIP CAP | 0603 | 27 pF* |  |  |  |  | Top
L5 | 1 |  | INDC1608X95N | 47 nH* |  |  |  |  | Top
C60 | 1 | SMD CHIP CAP | 0603 | 16 pF* |  |  |  |  | Top

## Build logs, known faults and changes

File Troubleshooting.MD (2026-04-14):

Troubleshooting
=====

# Stuttering Audio / Corrupted DAB Stream

Check that the Main SRAM is properly soldered, poor solder joints will cause stuttering and cutting out audio. This is especially the case if you find that it improves/gets worse if you move the board. This will also manifest as Frame errors in the DAB stream when using Welle.io. See the Important Notes for more information.

# No PLL Lock LED / Status in Config Page shows Unknown 00

Ensure that the 0Ohm Resistor at R20 is populated. This provides 3v3 to the DAC via IC5 and is required for the DAC to operate. 
Ensure that Oscillator is correctly installed and configured. If using the VCTCXO oscillator must be set to 19.4Mhz in the EasyDAB configuration, if using the non-VCTC Oscillator, then it must be configured for 24.576Mhz. The VCTCXO is polarized, ensure it is correctly orientated, if it is hot to touch, it has been installed the wrong way around. 
The OOhm Solder Pads R32/R33 are jumpers to specify which oscillator to use, if using the VCTCXO bridge R33, if using non-VCTCXO bridge R32. 

# No RF Output

Verify that IC7 has a voltage, and is correctly soldered. If using the Band Pass Filter, verify solder connections as they can easily be missed due to the solder pads for the component largely being on the bottom of the filter.
Check and replace the Low-Noise Amplifier IC7. 

# Booting LED stays on

If the Booting LED stays lit, the FPGA has not picked up the EasyDAB core. Verify your SPI flash is correctly programmed and replace if needed. 

# ETI Wait Light occasionally flashes solid/bright and RF drops

The buffer for the EasyDAB is not sufficient to maintain a stable output. Install additional SRAMs for the extra buffer. 

# ETI Wait Light Dimly Flickers
This is normal operation and indicating that the EasyDAB is processing an active ETI/ZMQ Stream. This is expected behavior on the 2017 firmware, but is not present on earlier firmwares.

# SFN and ODR-DabMux 

ODR-DabMux does not support EasyDAB's SFN after version 2.3.1, however later versions work fine if you are NOT using SFN. As far as I know this is due to ODR-DabMux changing how it handles creating timestamps of data allowing multiple EasyDABs to stay in sync. 

# FIR Clipped Indicator/ iFFT Overflow Happened

I have no idea what this is warning about, but it does not appear to impact operation.

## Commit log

2026-02-18 Uploading KiCad Converted Schematic
    [EasyDAB v2 Rev.6 Schematic.kicad_sch]
2026-02-18 Uploading Corrected Spreadsheet
    GPS DNI Components moved to correct sheet.
    [EasyDAB BoM W. Assembly Opts.xlsx]
2026-02-23 Adding files for flashing direct to the SPI Flash
2026-02-23 Adding in Gerber Zip
2026-04-14 Adding board renders
2026-04-14 Update README with Board Renders
